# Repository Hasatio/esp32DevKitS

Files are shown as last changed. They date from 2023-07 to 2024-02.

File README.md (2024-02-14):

# ESP32-DEVKIT-S

The circuit taken as an example while designing the board [Thing Plus C - ESP32 WROOM](https://www.sparkfun.com/products/retired/18018)

This pcb scaled down using the components in the example schematic

## Revision 0

### Added:

- 1x ADXL345 (Accelerometer)
- 2x 1x20 FPC connector for ESP pins
- In breakable PCB:
  - 4x ADS1115 (Analog to Digital Converter)
  - 1x20 FPC connector
  - 1x QWIIC connector

### Changed:

- ESP32-WROOM-32D model
- Battery socket breakable PCB
- Logo

### Removed:

- RGB led
- SD card

### Note: The connection cannot be made because the tx rx connection paths are not correct.

## Revision 1

- Two circuits were produced for the left and right foot.

### Added:
- New circuit in mirror image design

### Changed:
- Circuit design, components in usb communication and components in the power section
- CH340C model
- TX, RX connection paths reversed
- Analog pull up resistor 100k

### Note: The battery does not charge when the switch is in the off position.

## Revision 2

### Changed:
- The on/off switch will only be used for battery discharge

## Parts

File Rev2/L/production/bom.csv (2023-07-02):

Designator | Footprint | Quantity | Value | LCSC Part #
_2, |  | 2
C15, C16, C17, C22, C23, C24, C25, C27 | 0402-TIGHT | 8 | 1.0uF
C18, C19 | 0402-TIGHT | 2 | 10uF
C20, C21 | 0402-TIGHT | 2 | 4.7uF
C26, C28 | 0402-TIGHT | 2 | 0.1uF
D5 | SOD-323 | 1 | S4 3A/10V/280mV
D6 | LED-0603 | 1 | RED
D7 | LED-0603 | 1 | Yellow
D8 | LED-0603 | 1 | BLUE
FRAME1 | CREATIVE_COMMONS | 1 | FRAME-LEDGER
J10, J13 | JST04_1MM_RA | 2 | QWIIC_RIGHT_ANGLE
J11, J12, J14 | Molex_200528-0200_1x20-1MP_P1.00mm_Horizontal | 3 | Conn_01x20
J8 | JST-2-SMD | 1 | JST_2MM_MALE
J9 | USB-C-16P-2LAYER-PADS | 1 | USB_C_2-LAYER_PADS
JP3, JP4 | SMT-JUMPER_2_NC_TRACE_SILK | 2 | JUMPER-SMT_2_NC_TRACE_SILK
Q3 | SOT23-3 | 1 | DMG2305UX 20V/4.2A/52mΩ/1.4W
Q4 | SC70-6 | 1 | MBT3904DW1T1
R32, R34, R35, R38, R39, R57 | 0402-TIGHT | 6 | 10k
R33, R36, R37 | 0402-TIGHT | 3 | 4k7
R40, R58, R62 | 0402-TIGHT | 3 | 1k
R41, R42, R43, R44, R45, R46, R47, R48, R49, R50, R51, R52, R53, R54, R55, R56 | 0402-TIGHT | 16 | 150k
R59 | 0402-TIGHT | 1 | 2.0k
R60, R61 | 0402-TIGHT | 2 | 5.1k
S3 | TACTILE_SWITCH_SMD_2.8X1.9MM | 1 | Boot
S4 | TACTILE_SWITCH_SMD_2.8X1.9MM | 1 | Reset
SW2 | SW_SPDT_k3-1295 | 1 | ON/OFF
U11 | LGA-14_3x5mm_P0.8mm_LayoutBorder1x6y | 1 | ADXL345
U12 | SOT23-5 | 1 | AP2112K-3.3
U13 | ESP-WROOM-32-NARROW | 1 | >VALUE
U14 | SOT23-5 | 1 | MCP73831
U15, U16, U17, U18 | TSSOP-10_3x3mm_P0.5mm | 4 | ADS1115IDGS
U19 | SOIC-16_3.9x9.9mm_P1.27mm | 1 | CH340C
U20 | DFN-8 | 1 | MAX17048

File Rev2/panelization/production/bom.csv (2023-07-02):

Designator | Footprint | Quantity | Value | LCSC Part #
_5, _4, _3, _2, |  | 5
C1, C10, C11, C13, C15, C16, C17, C2, C22, C23, C24, C25, C27, C3, C8, C9 | 0402-TIGHT | 16 | 1.0uF
C12, C14, C26, C28 | 0402-TIGHT | 4 | 0.1uF
C18, C19, C4, C5 | 0402-TIGHT | 4 | 10uF
C20, C21, C6, C7 | 0402-TIGHT | 4 | 4.7uF
D1, D5 | SOD-323 | 2 | S4 3A/10V/280mV
D2, D6 | LED-0603 | 2 | RED
D3, D7 | LED-0603 | 2 | Yellow
D4, D8 | LED-0603 | 2 | BLUE
J1, J8 | JST-2-SMD | 2 | JST_2MM_MALE
J10, J13, J3, J6 | JST04_1MM_RA | 4 | QWIIC_RIGHT_ANGLE
J11, J12, J14, J4, J5, J7 | Molex_200528-0200_1x20-1MP_P1.00mm_Horizontal | 6 | Conn_01x20
J2, J9 | USB-C-16P-2LAYER-PADS | 2 | USB_C_2-LAYER_PADS
JP1, JP2, JP3, JP4 | SMT-JUMPER_2_NC_TRACE_SILK | 4 | JUMPER-SMT_2_NC_TRACE_SILK
Q1, Q3 | SOT23-3 | 2 | DMG2305UX 20V/4.2A/52mΩ/1.4W
Q2, Q4 | SC70-6 | 2 | MBT3904DW1T1
R1, R26, R3, R32, R34, R35, R38, R39, R4, R57, R7, R8 | 0402-TIGHT | 12 | 10k
R10, R11, R12, R13, R14, R15, R16, R17, R18, R19, R20, R21, R22, R23, R24, R25, R41, R42, R43, R44, R45, R46, R47, R48, R49, R50, R51, R52, R53, R54, R55, R56 | 0402-TIGHT | 32 | 150k
R2, R33, R36, R37, R5, R6 | 0402-TIGHT | 6 | 4k7
R27, R31, R40, R58, R62, R9 | 0402-TIGHT | 6 | 1k
R28, R59 | 0402-TIGHT | 2 | 2.0k
R29, R30, R60, R61 | 0402-TIGHT | 4 | 5.1k
S1, S3 | TACTILE_SWITCH_SMD_2.8X1.9MM | 2 | Boot
S2, S4 | TACTILE_SWITCH_SMD_2.8X1.9MM | 2 | Reset
SW1, SW2 | SW_SPDT_k3-1295 | 2 | ON/OFF
U1, U11 | LGA-14_3x5mm_P0.8mm_LayoutBorder1x6y | 2 | ADXL345
U10, U20 | DFN-8 | 2 | MAX17048
U12, U2 | SOT23-5 | 2 | AP2112K-3.3
U13, U3 | ESP-WROOM-32-NARROW | 2 | >VALUE
U14, U4 | SOT23-5 | 2 | MCP73831
U15, U16, U17, U18, U5, U6, U7, U8 | TSSOP-10_3x3mm_P0.5mm | 8 | ADS1115IDGS
U19, U9 | SOIC-16_3.9x9.9mm_P1.27mm | 2 | CH340C

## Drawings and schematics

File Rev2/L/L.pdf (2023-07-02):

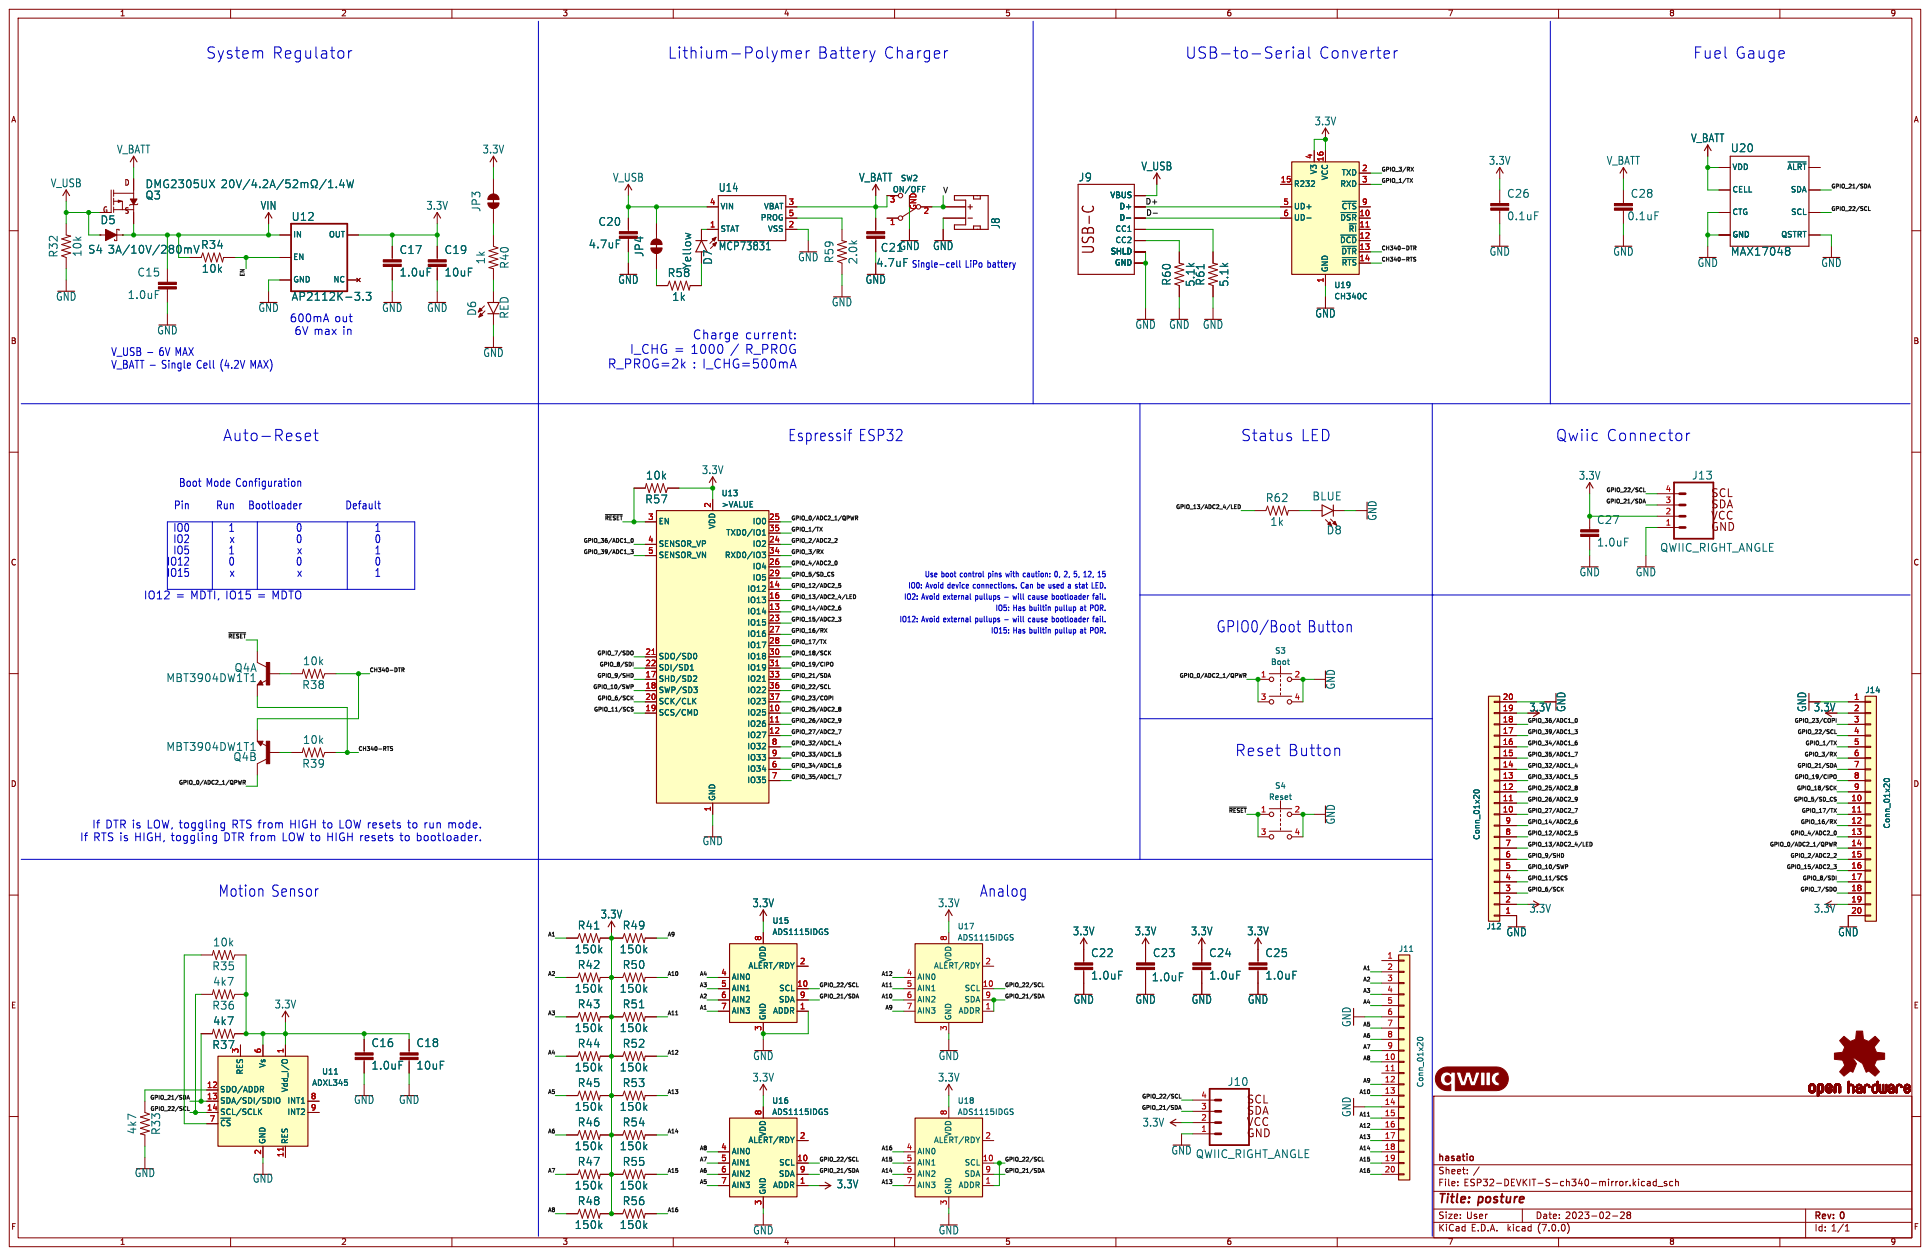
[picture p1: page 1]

~{ALRT} QSTRT SCL SDA U20
CELL VDD GND

1 ~{DSR} 10 ~{RI} 11 ~{DCD} 12 ~{DTR} 13 ~{RTS} 14 R232 15 VCC 16 TXD 2 RXD 3 V3

8 SDA 9 U17 ADS1115IDGS GND USB-CCC1 D+D- CC2 GND

Run
IO12: Avoid external pullups - will cause bootloader fail. x

2 SCK/CLK 20 SDO/SD0 21 SDI/SD1 22

GPIO_23/COPI GPIO_22/SCL GPIO_25/ADC2_8 GPIO_26/ADC2_9 GPIO_22/SCL GPIO_21/SDA GPIO_21/SDA

IO2: Avoid external pullups - will cause bootloader fail.

IO5: Has builtin pullup at POR.

IO15: Has builtin pullup at POR. R55

GPIO_1/TX GPIO_22/SCL GPIO_23/COPI GPIO_22/SCL

If DTR is LOW, toggling RTS from HIGH to LOW resets to run mode.
If RTS is HIGH, toggling DTR from LOW to HIGH resets to bootloader.

File: ESP32-DEVKIT-S-ch340-mirror.kicad_sch Sheet: / hasatio GND

3 AIN0 4 AIN1 5 AIN2 6 AIN3 7 VDD
ADDR 1 SCL 10 ALERT/RDY 2 GND

1 RES 11 SDO/ADDR 12 SDA/SDI/SDIO 13 SCL/SCLK 14 GND

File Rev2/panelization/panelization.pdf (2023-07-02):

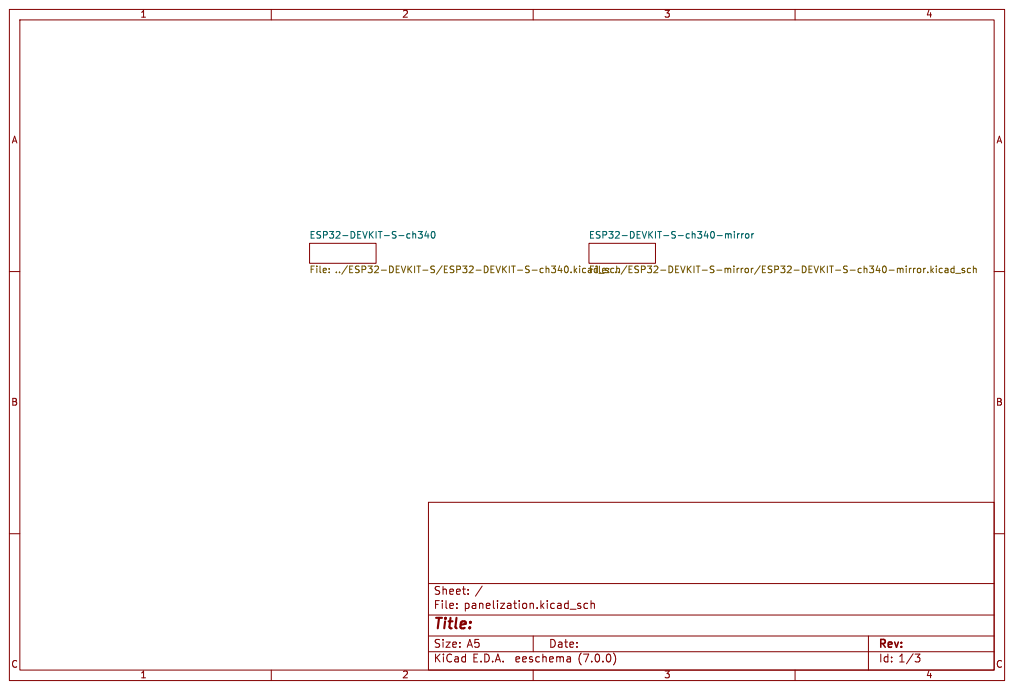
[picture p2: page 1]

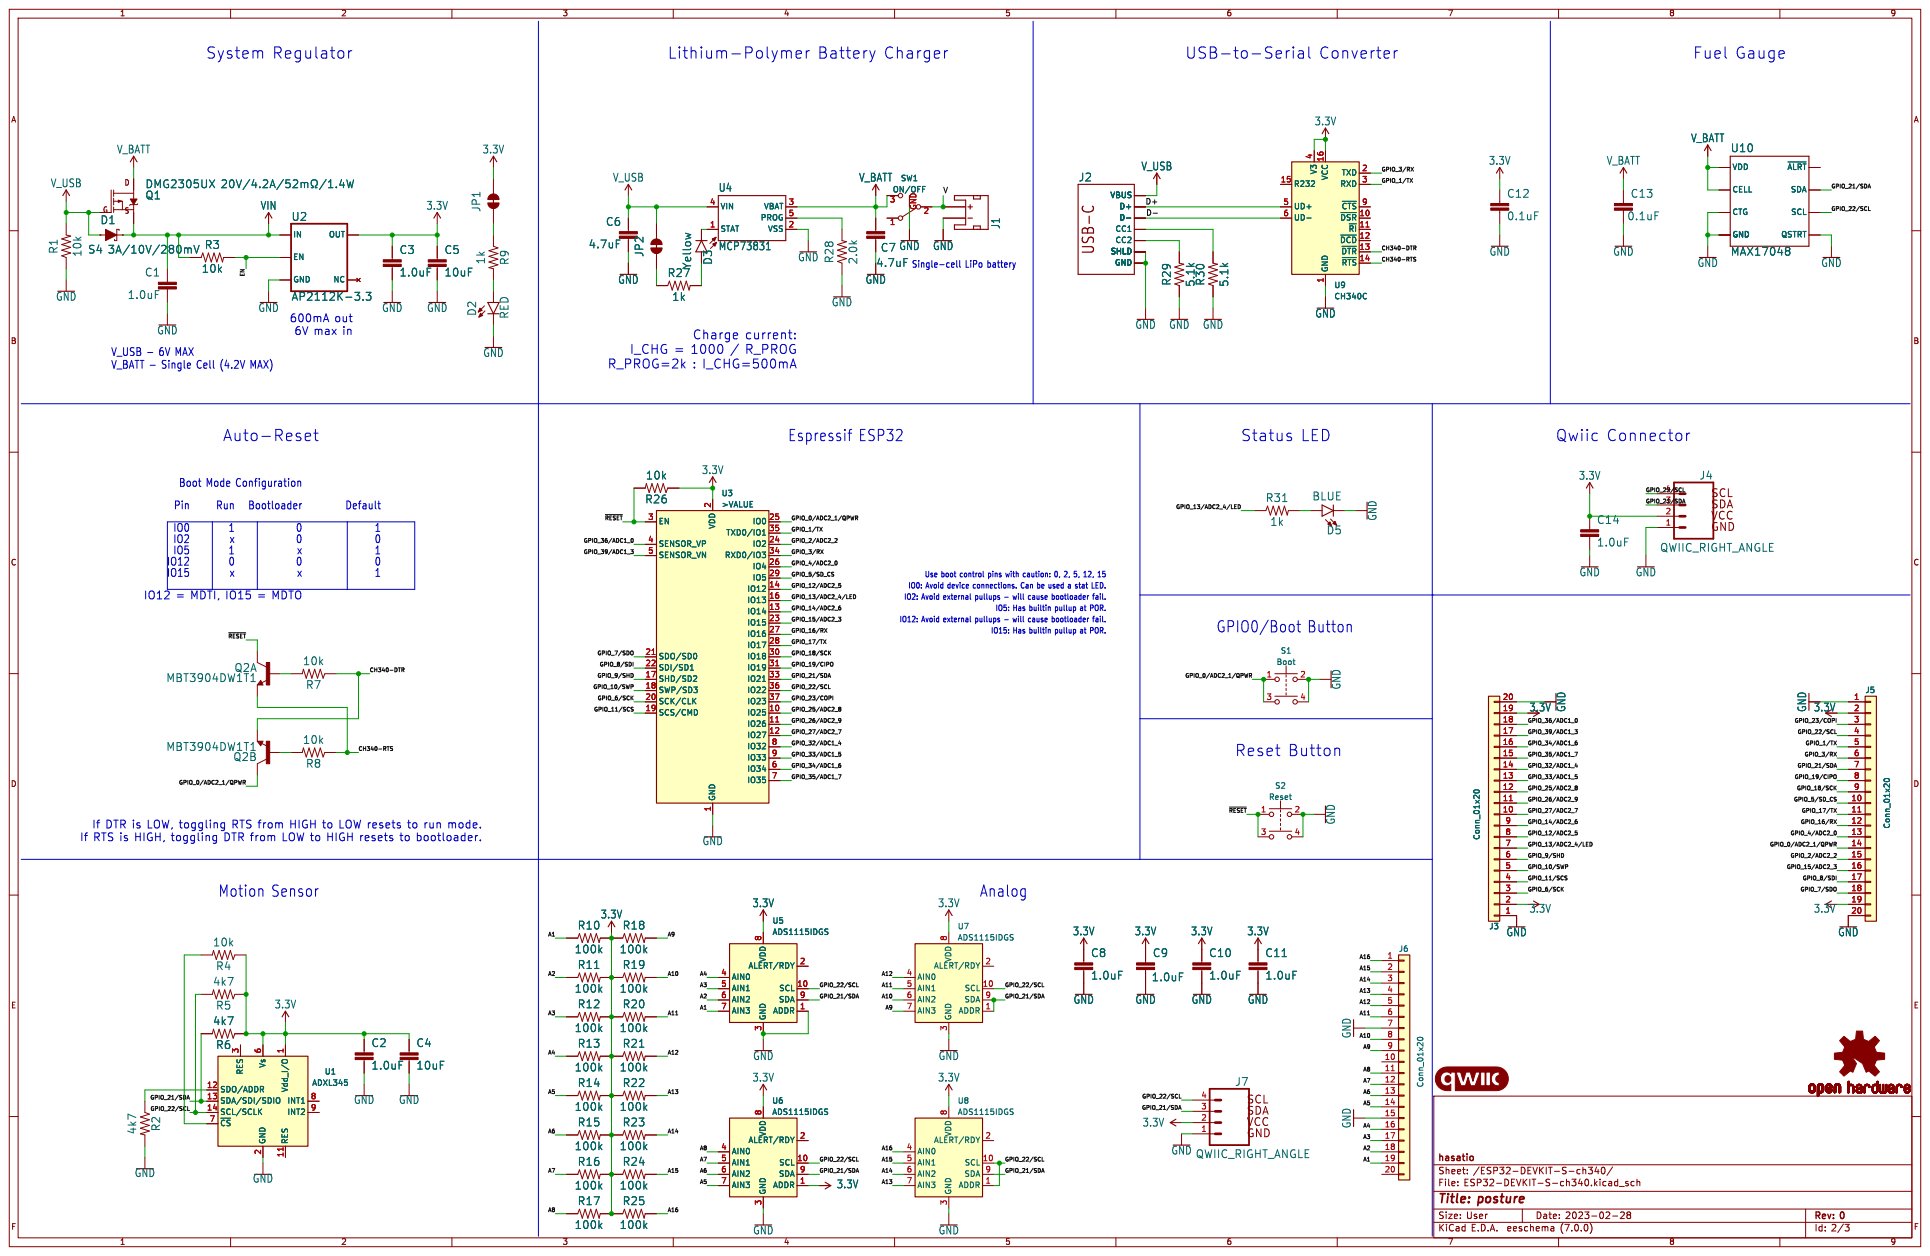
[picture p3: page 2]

~{ALRT} QSTRT SCL SDA V_BATT
CELL VDD GND

~{ALRT} QSTRT SCL SDA U10

4 UD+ 5 UD- 6 ~{CTS}9 U9 CH340C GND

4 UD+ 5 UD- 6 ~{CTS}9 GND R30 5.1k

1 ~{DSR} 10 ~{RI} 11 ~{DCD} 12 ~{DTR} 13 ~{RTS} 14 R232 15 VCC 16 TXD 2 RXD 3 V3

2 SCK/CLK 20 SDO/SD0 21 SDI/SD1 22

IO15: Has builtin pullup at POR. Use boot control pins with caution: 0, 2, 5, 12, 15

IO12: Avoid external pullups - will cause bootloader fail. Analog

If DTR is LOW, toggling RTS from HIGH to LOW resets to run mode.
If RTS is HIGH, toggling DTR from LOW to HIGH resets to bootloader.

3 AIN0 4 AIN1 5 AIN2 6 AIN3 7 VDD
ADDR 1 SCL 10 ALERT/RDY 2 GND

File: ESP32-DEVKIT-S-ch340.kicad_sch Sheet: /ESP32-DEVKIT-S-ch340/ hasatio 3.3V

1 RES 11 SDO/ADDR 12 SDA/SDI/SDIO 13 SCL/SCLK 14 GND

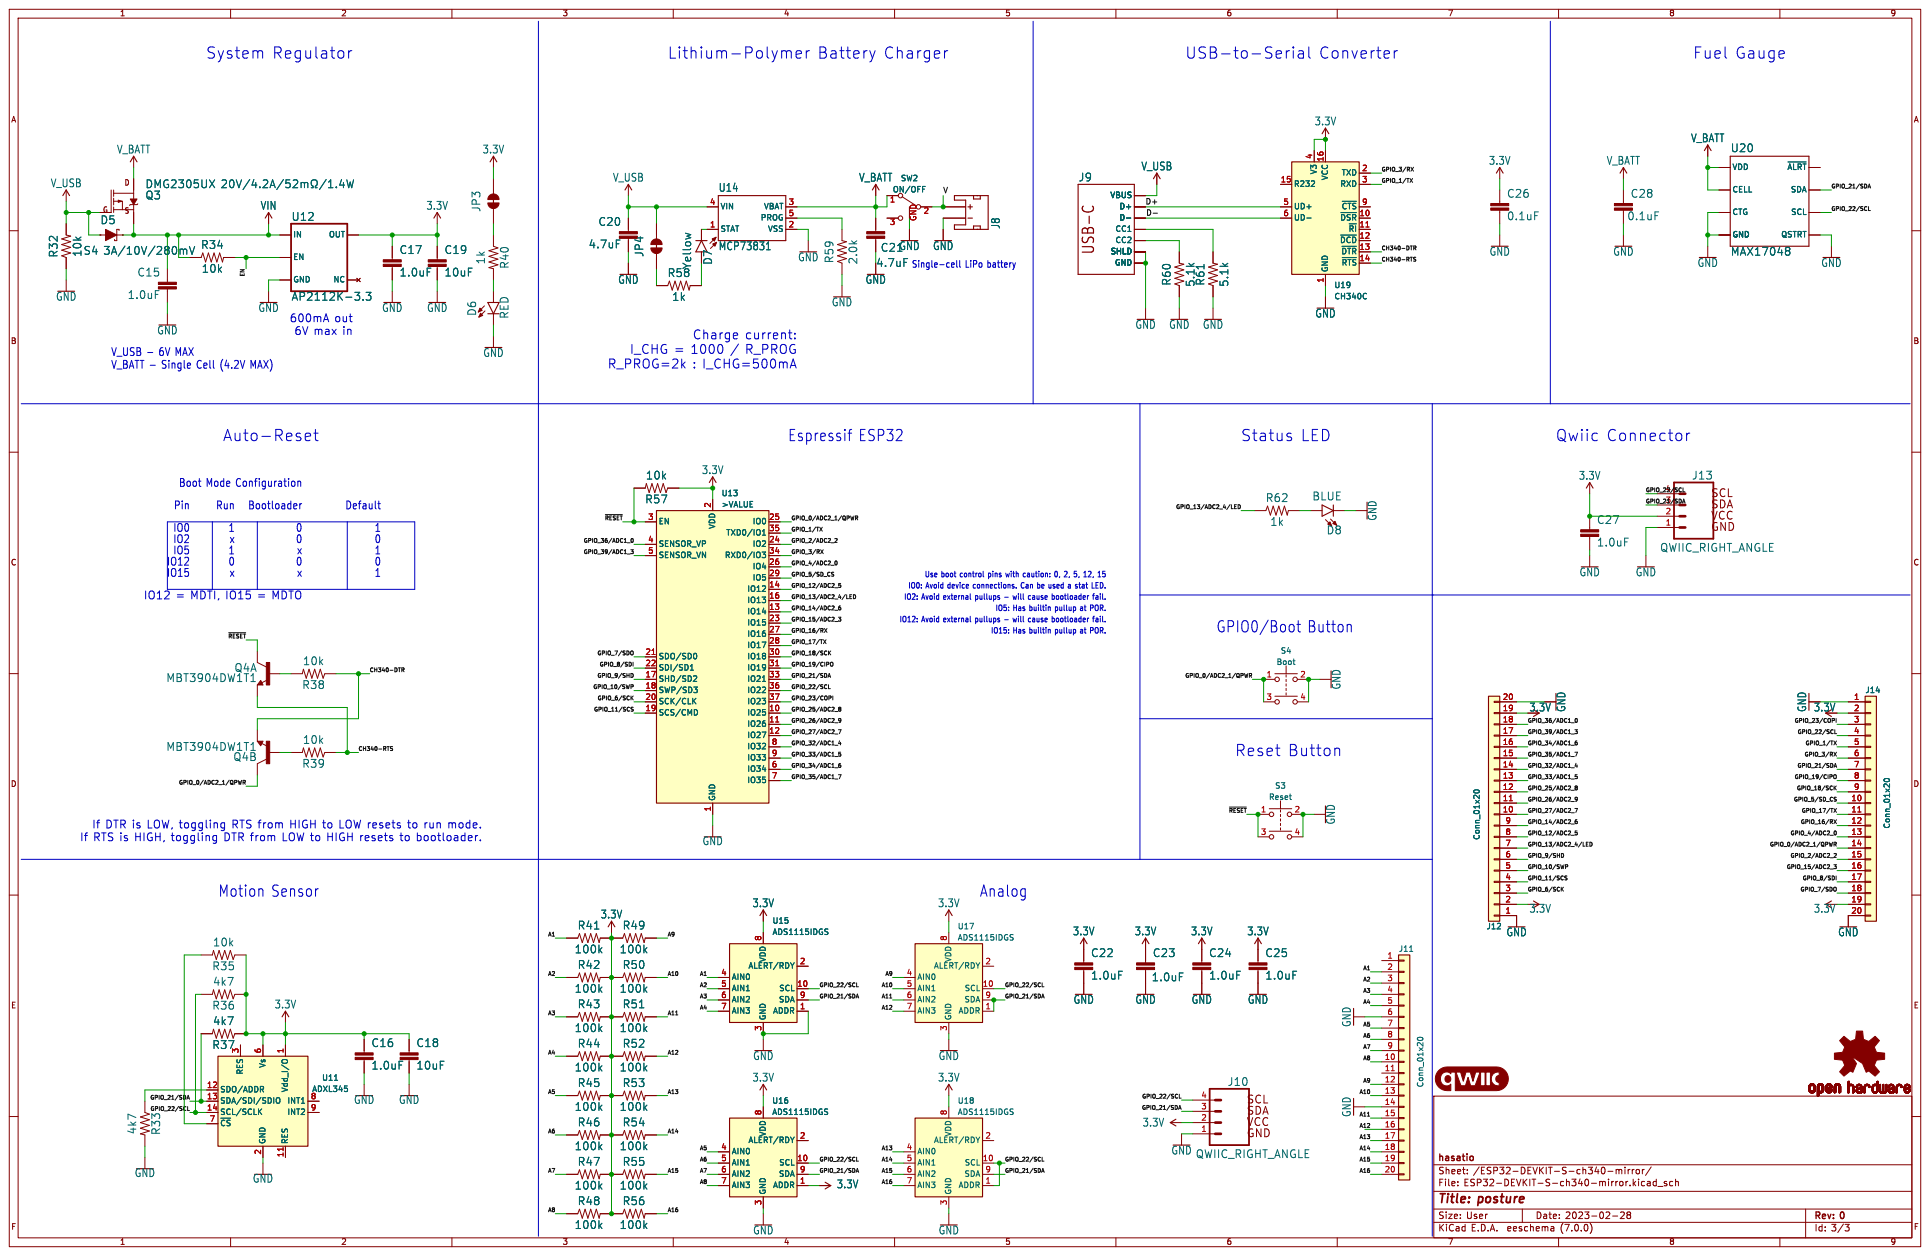
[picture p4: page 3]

GPIO_1/TX GPIO_3/RX CH340-RTS CH340-DTR

~{ALRT} QSTRT SCL SDA U20

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

4 UD+ 5 UD- 6 ~{CTS}9 GND

IO12: Avoid external pullups - will cause bootloader fail. Use boot control pins with caution: 0, 2, 5, 12, 15 Default

2 SCK/CLK 20 SDO/SD0 21 SDI/SD1 22

GPIO_0/ADC2_1/QPWR GPIO_4/ADC2_0 GPIO_5/SD_CS GPIO_12/ADC2_5 GPIO_26/ADC2_9 GPIO_32/ADC1_4 GPIO_25/ADC2_8 GPIO_27/ADC2_7 GPIO_15/ADC2_3 GPIO_16/RX GPIO_17/TX GPIO_14/ADC2_6 GPIO_19/CIPO

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

GPIO_9/SHD GPIO_6/SCK GPIO_11/SCS GPIO_10/SWP

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

1 RES 11 SDO/ADDR 12 SDA/SDI/SDIO 13 SCL/SCLK 14 GND

File: ESP32-DEVKIT-S-ch340-mirror.kicad_sch Sheet: /ESP32-DEVKIT-S-ch340-mirror/ hasatio

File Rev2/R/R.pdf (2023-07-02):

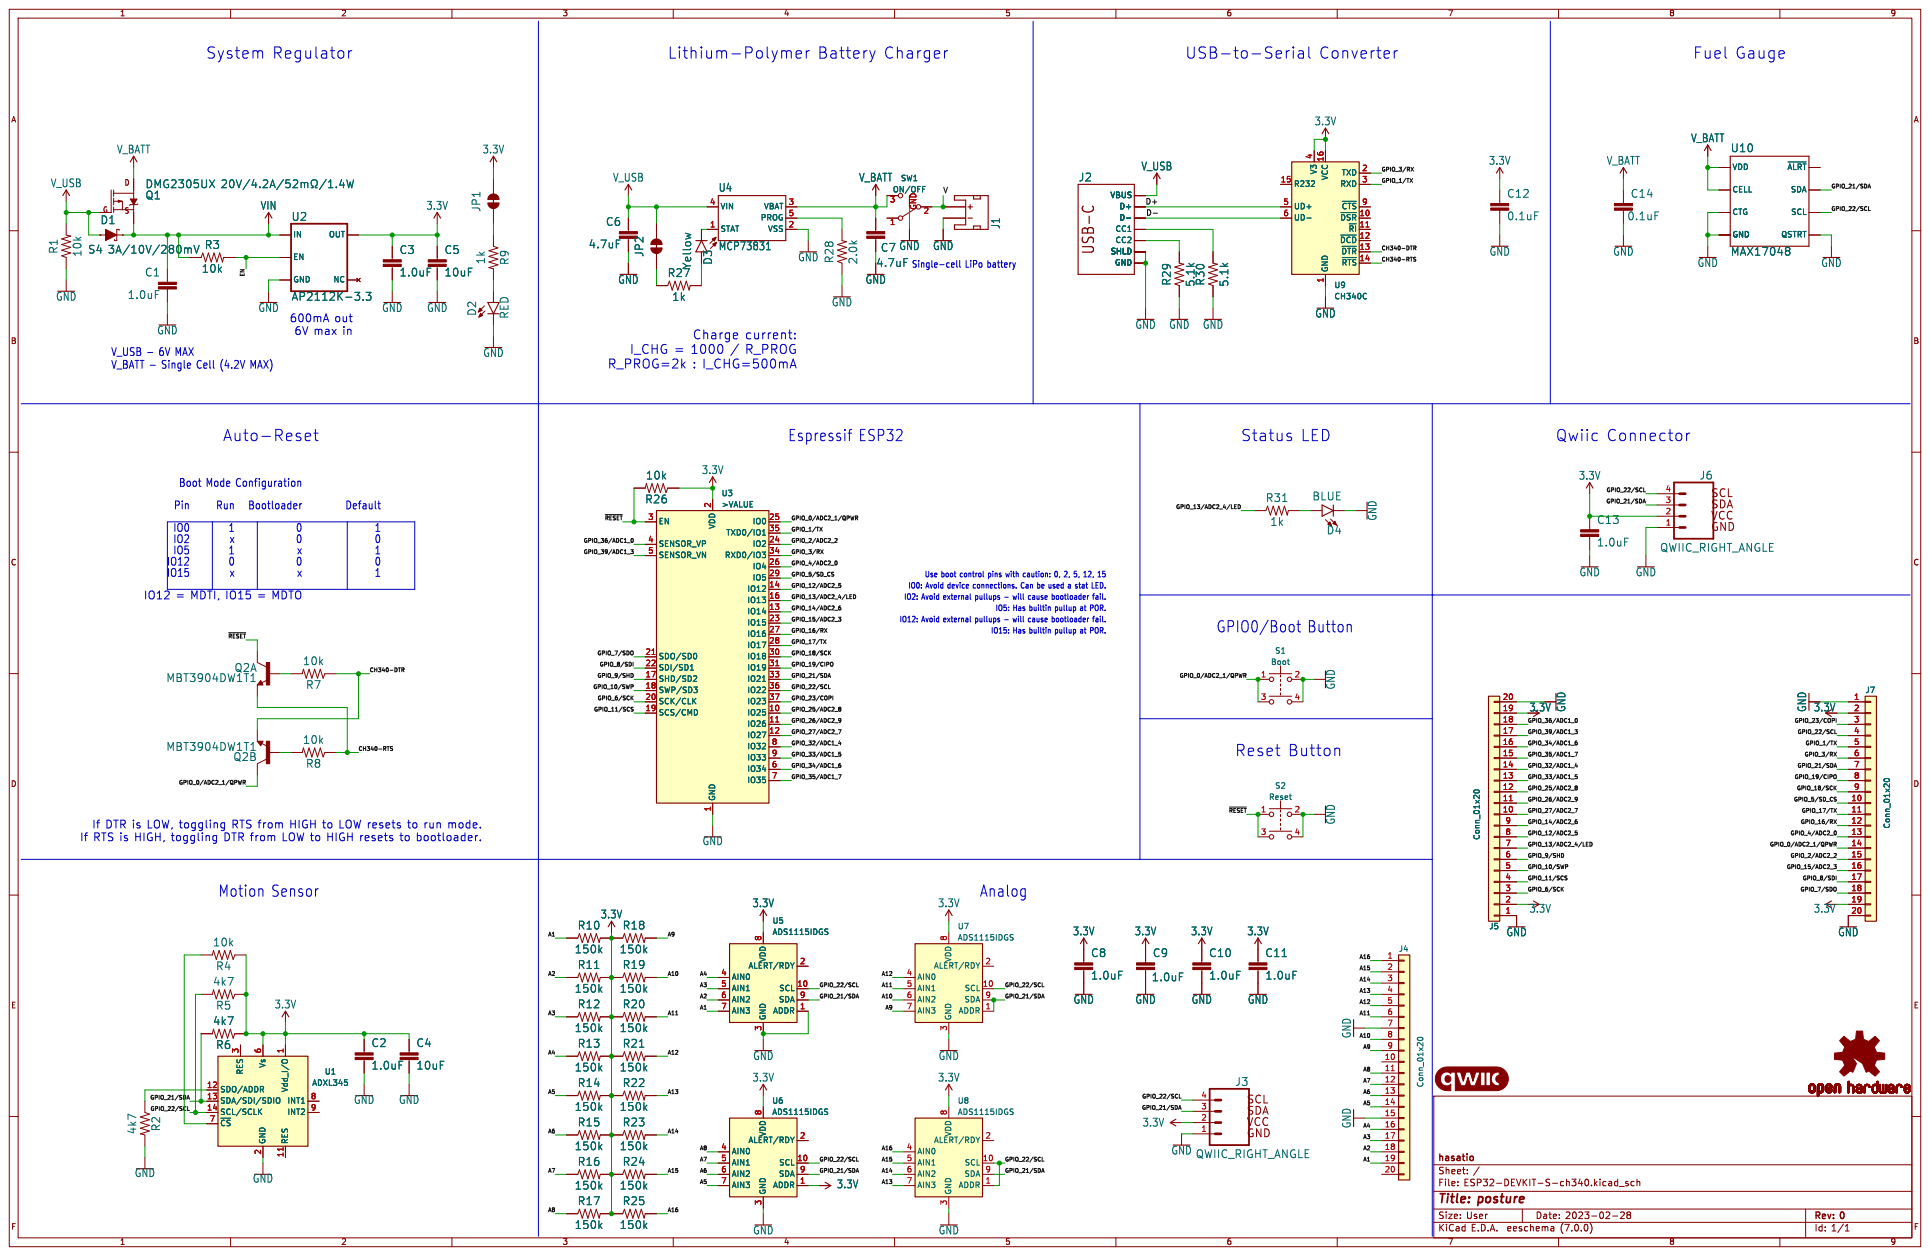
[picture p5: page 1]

~{ALRT} QSTRT SCL SDA V_BATT
CELL VDD GND

~{ALRT} QSTRT SCL SDA U10

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

Boot Mode Configuration
IO12: Avoid external pullups - will cause bootloader fail. IO5
IO2: Avoid external pullups - will cause bootloader fail. IO12
IO12 = MDTI, IO15 = MDTO

IO5: Has builtin pullup at POR. Analog

2 SCK/CLK 20 SDO/SD0 21 SDI/SD1 22

IO15: Has builtin pullup at POR.

GPIO_8/SDI GPIO_6/SCK GPIO_10/SWP GPIO_11/SCS GPIO_9/SHD

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

1 RES 11 SDO/ADDR 12 SDA/SDI/SDIO 13 SCL/SCLK 14 GND

File: ESP32-DEVKIT-S-ch340.kicad_sch Sheet: / hasatio

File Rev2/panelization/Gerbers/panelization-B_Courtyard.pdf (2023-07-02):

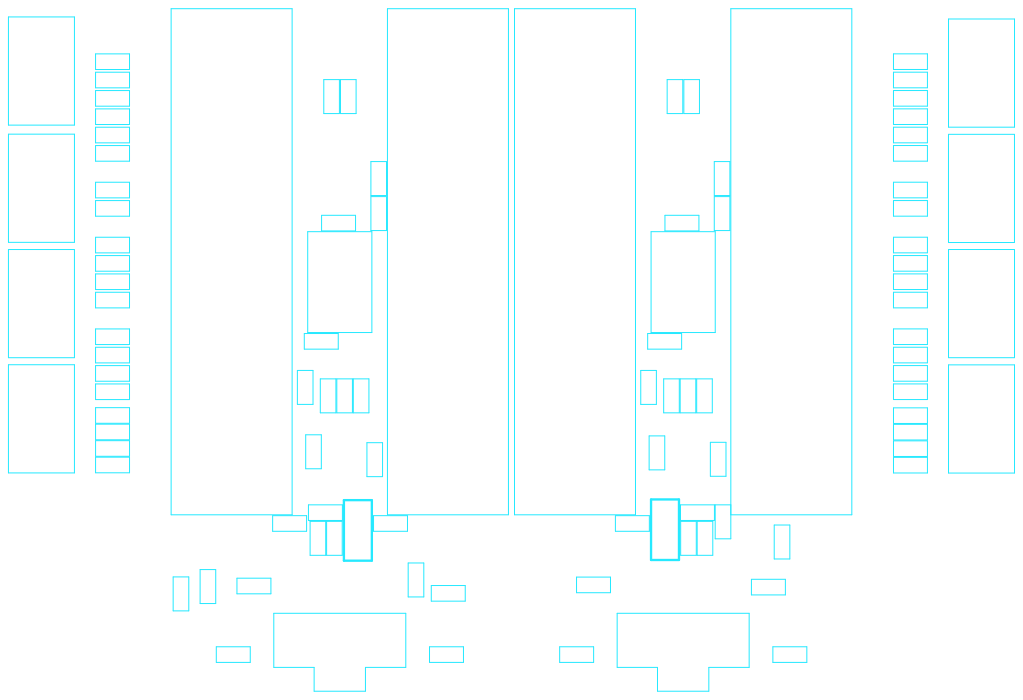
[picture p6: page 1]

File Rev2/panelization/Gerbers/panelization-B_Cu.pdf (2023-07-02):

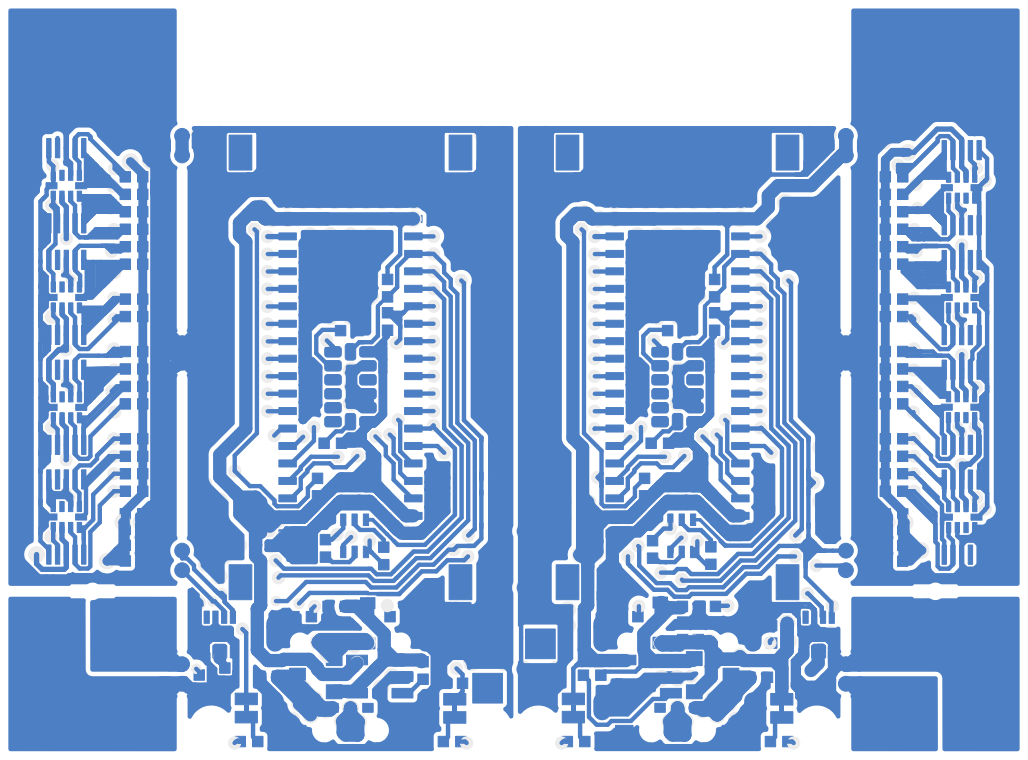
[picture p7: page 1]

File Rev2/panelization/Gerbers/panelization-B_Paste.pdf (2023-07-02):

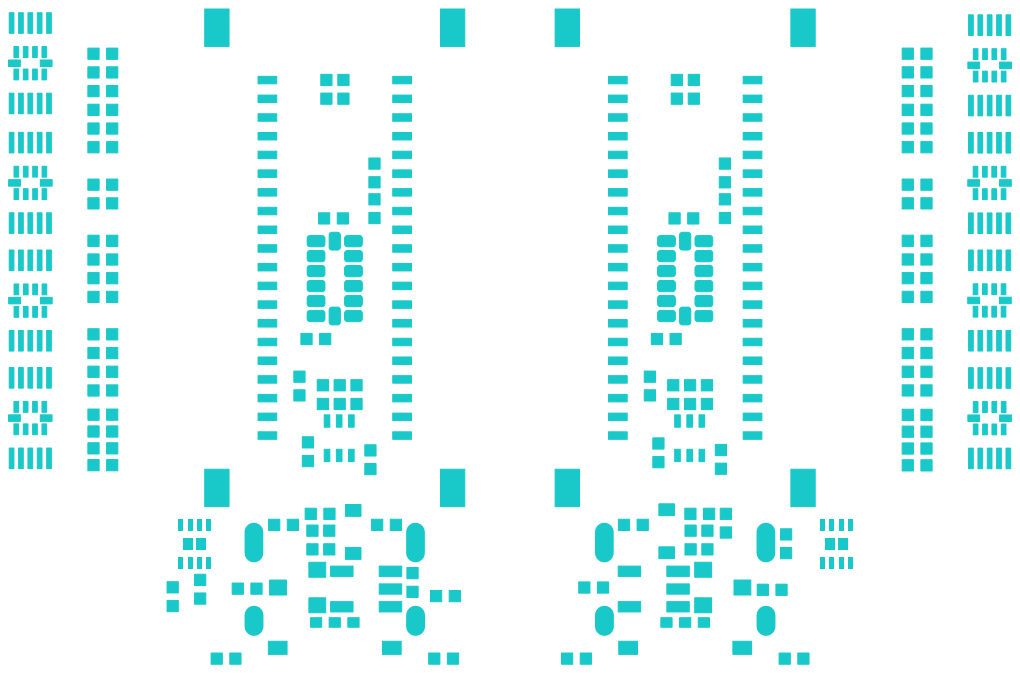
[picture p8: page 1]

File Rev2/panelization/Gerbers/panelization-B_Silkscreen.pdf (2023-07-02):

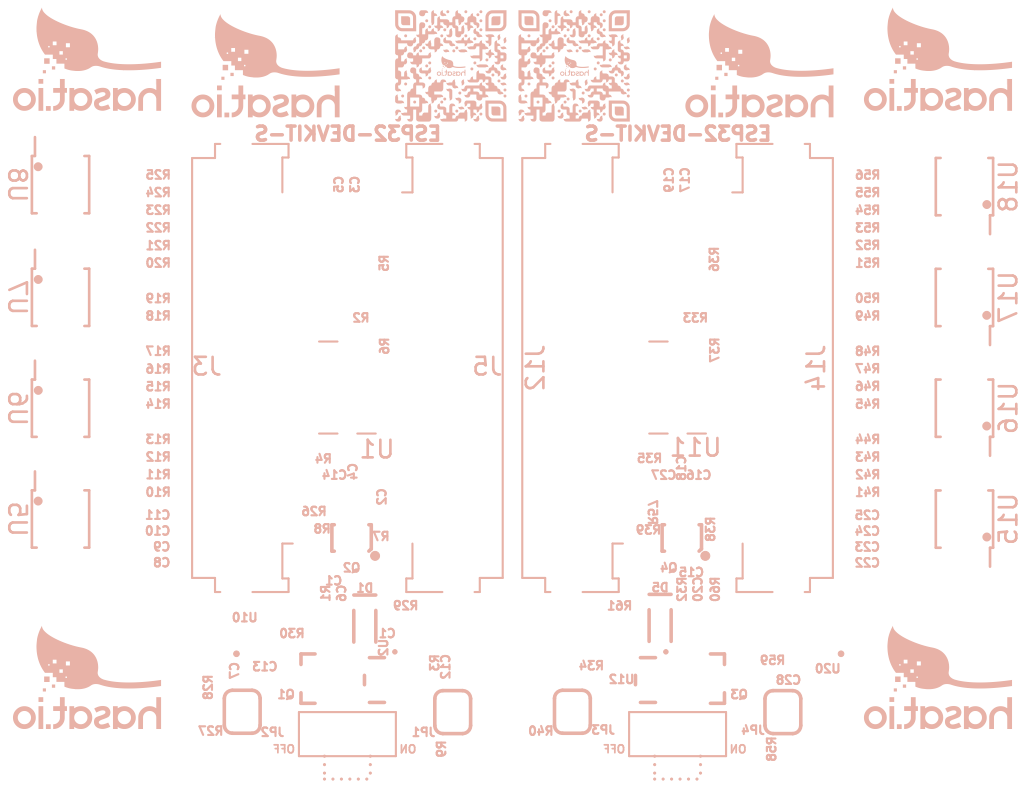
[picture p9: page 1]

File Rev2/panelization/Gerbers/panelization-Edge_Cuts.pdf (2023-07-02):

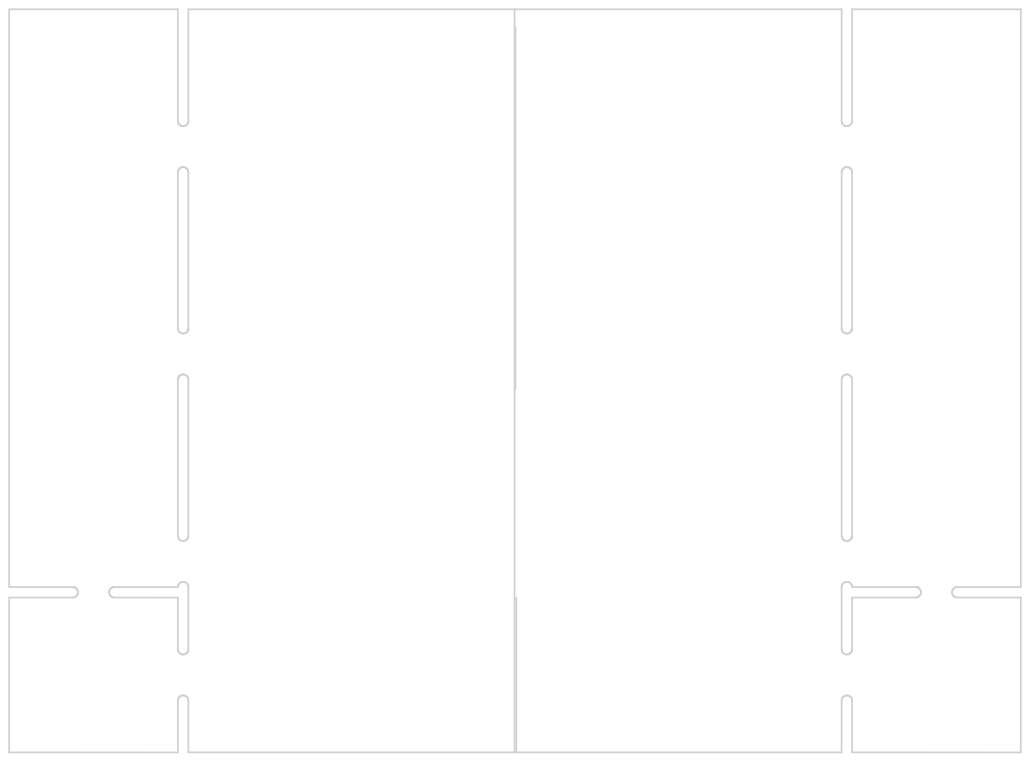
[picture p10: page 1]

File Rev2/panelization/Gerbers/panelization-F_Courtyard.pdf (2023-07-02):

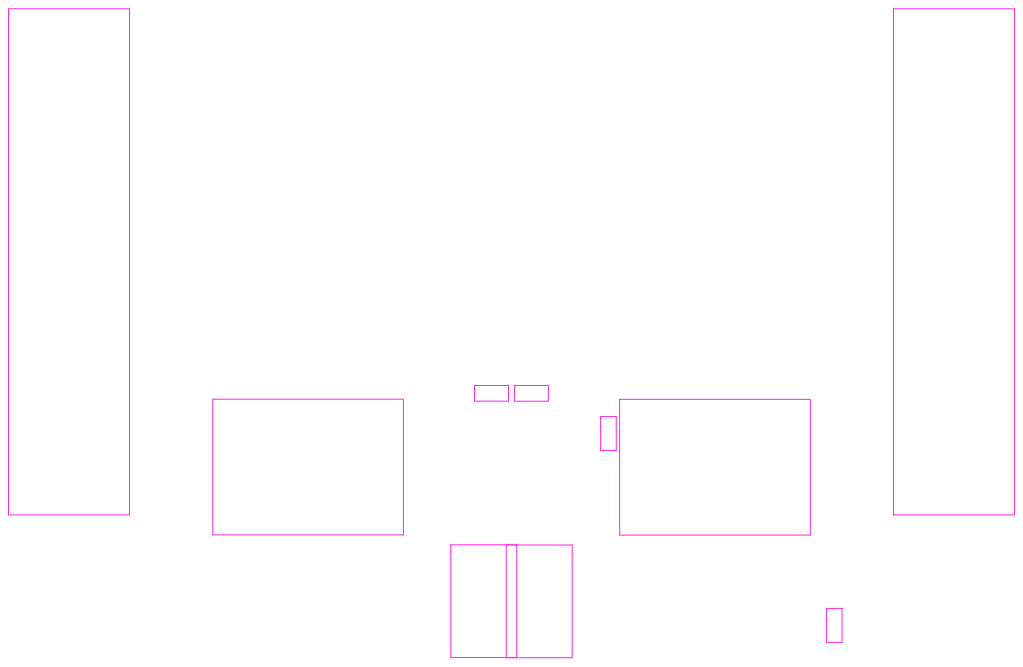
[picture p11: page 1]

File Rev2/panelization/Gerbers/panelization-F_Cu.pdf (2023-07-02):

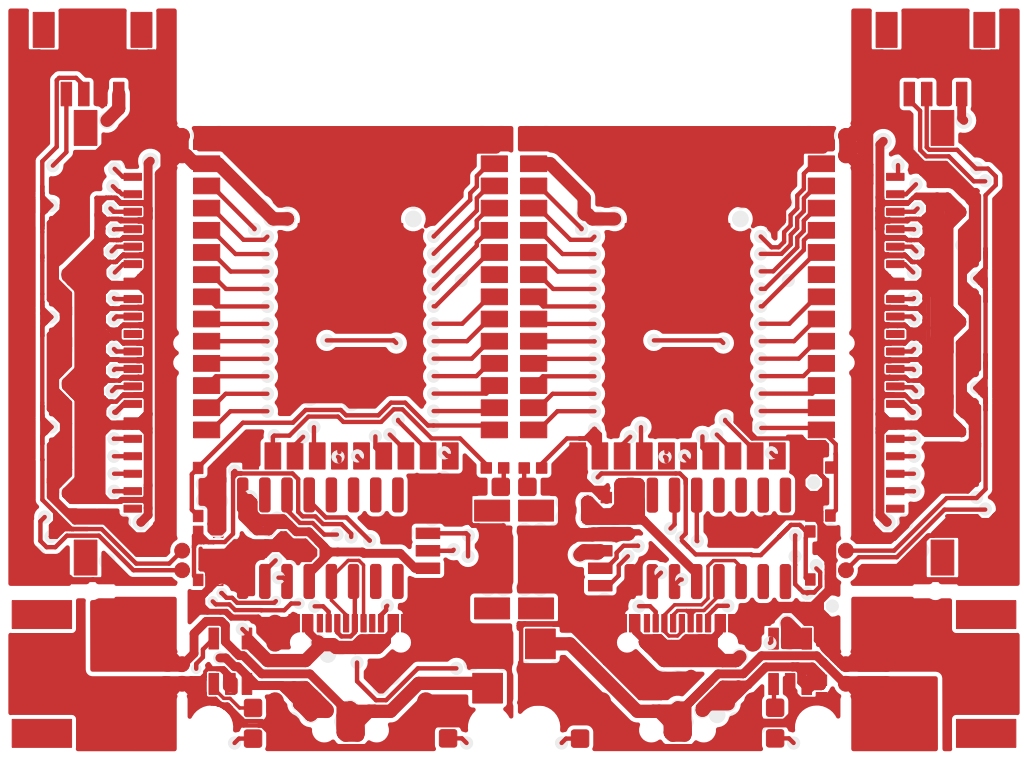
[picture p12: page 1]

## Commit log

2023-03-15 add logo and qr
    [ESP32-DEVKIT-S.kicad_pcb, bom.csv, designators.csv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]
2023-03-15 add battery pin
    [ESP32-DEVKIT-S.kicad_pcb, positions.csv]
2023-03-16 17.03.23
    cp2102 yerine ch340 ekledim
    [ESP32-DEVKIT-S-ch340.kicad_pcb, ESP32-DEVKIT-S-ch340.kicad_sch, ESP32-DEVKIT-S-cp2102.kicad_pcb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]
2023-04-26 add mirror
    [ESP32-DEVKIT-S-ch340-mirror.kicad_pcb, ESP32-DEVKIT-S-ch340-mirror.kicad_sch, ESP32-DEVKIT-S-ch340.kicad_pcb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]
